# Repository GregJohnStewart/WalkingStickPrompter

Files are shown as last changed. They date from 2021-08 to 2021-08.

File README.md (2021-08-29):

# WalkingStickPrompter

A walking stick tele-prompter.

## Usage

### SD Card

The SD card has several "gotcha's":

- Must be formatted as `FAT` (preferably `FAT16`, but `FAT32` should work as well) 
- Directories currently not supported
- Keep the SD relatively clean, not too many files. For file selection need all the file names read in and there isn't a ton or RAM to go around!
  - One shouldn't have more than 13 `.txt` files available, as the menu system doesn't currently support scrolling

Resources:

- https://www.arduino.cc/en/Reference/SDCardNotes

### Files

These are guidelines for files that are on the sd card. For the device to operate properly, you must keep these things in mind.

- File names:
  - Case insensitive; `hello.txt` will be seen the same as `Hello.txt` and the board will get confused.
  - can only be 8 characters long, or will be shortened artificially in the display. Unfortunately, with the tech used there isn't a way around this.
  - sometimes a file can get weird, and fail to read. try renaming it.
- File Formats:
  - Currently, only `.txt` files are accepted.
  - The files must be pre-formatted before they will display correctly
    - Essentially, newlines will mess up how the text is displayed on the screen, moving all text under the newline down (and out of view)
    - There is a tool though for formatting the files appropriately: [Formatter](Formatter.html)
- The device will save the options set by the user to the SD card using the `OPS.DAT` file. This is not meant to be edited manually, but can be deleted to reset the options to default.

Resources:

- https://www.arduino.cc/en/Reference/SDCardNotes

### Battery

On preliminary measurements, will full brightness and smallest text size, the device lasted ____ on a 1200mAh battery.

To charge the battery, simply plug the main board into the computer or phone charger, with the battery plugged in and on (if a switch was added between the battery and the board). The main board will handle charging the battery.

The Orange light on the board is an indicator for charging status:

- Off = Not charging, fully charged
- On = Charging
- Flashing = No battery connected

More information here: https://learn.adafruit.com/adafruit-feather-328p-atmega328-atmega328p/power-management

### How to Use

The board uses a simple menu system to navigate. When the device is powered on, it first displays a splash screen. After that, it will go into the file select menu.

#### File Selection

This menu shows all valid and available text files for reading.

Use <kbd>Up</kbd> or <kbd>Down</kbd> to highlight a file, <kbd>Right</kbd> to select it (moving into file reading).

Pressing <kbd>Left</kbd> will send you to the Options Menu

#### File Reading

When reading a file, it will simply display one page of file content at a time.

- <kbd>Down</kbd> will load the next page

- <kbd>Up</kbd> will load the previous page
- <kbd>Left</kbd> will send you back to File Selection

#### Options Menu

The Options menu will let you change the presentation of text when reading files in.

Use <kbd>Up</kbd> or <kbd>Down</kbd> to highlight an option to change, <kbd>Right</kbd> to select it (moving to that option's specific menu).

Pressing <kbd>Left</kbd> will send you back to File Select.

##### Text Size

The text size menu will change the size of the text when file reading.

Use <kbd>Up</kbd> or <kbd>Down</kbd> to cycle through the available sizes, <kbd>Right</kbd> to set the size to the current one shown.

Pressing <kbd>Left</kbd> will send you back to the Options menu without saving changes.

##### Text Color

The text size menu will change the color of the text when file reading.

Use <kbd>Up</kbd> or <kbd>Down</kbd> to hilight the available colors, <kbd>Right</kbd> to set the color to the current one selected.

Pressing <kbd>Left</kbd> will send you back to the Options menu without saving changes.

##### Backlight

The text size menu will change the backlight level of the screen.

Use <kbd>Up</kbd> or <kbd>Down</kbd> to cycle through the available brightnesses, <kbd>Right</kbd> to set the brightness to the current one shown.

Pressing <kbd>Left</kbd> will send you back to the Options menu without saving changes.

## Build Documentation

### Bill of Materials

- [Adafruit Feather 328P](https://learn.adafruit.com/adafruit-feather-328p-atmega328-atmega328p/overview)
- [2.2" 18-bit color TFT LCD display with microSD card breakout](https://www.adafruit.com/product/1480)
- 4 momentary switches, or a d-pad
- 1 snap switch for battery (optional)

### Resources

- [Adafruit Feather 328P Pinouts](https://learn.adafruit.com/adafruit-feather-328p-atmega328-atmega328p/pinouts)
- [Adafruit 2.2" TFT Display with SD Card Reader](https://learn.adafruit.com/2-2-tft-display)
  - https://learn.adafruit.com/2-2-tft-display/adafruit-gfx-library
  - 
- [Adafruit ILI9341 Arduino Library](https://github.com/adafruit/Adafruit_ILI9341)
  - https://github.com/adafruit/Adafruit_ILI9341/blob/master/Adafruit_ILI9341.h
  - 
  - https://learn.adafruit.com/adafruit-gfx-graphics-library/overview
  - https://learn.adafruit.com/adafruit-gfx-graphics-library?view=all
  - https://www.arduino.cc/en/Reference/TFTSetTextSize
- [Arduino SD Library](https://github.com/arduino-libraries/SD)
  - https://github.com/arduino-libraries/SD/blob/master/src/utility/SdFile.cpp
  - https://github.com/arduino-libraries/SD/blob/master/src/File.cpp
  - https://github.com/adafruit/SD/blob/master/examples/Files/Files.ino
  - https://www.arduino.cc/en/Reference/SD
    - https://www.arduino.cc/en/Reference/FileRead
    - https://www.arduino.cc/en/Reference/FileSeek
- [Arduino Data Types](https://www.tutorialspoint.com/arduino/arduino_data_types.htm)
- [Adafruit TFT Display Example](https://github.com/adafruit/Adafruit_ILI9341/blob/master/examples/graphicstest/graphicstest.ino)
- [Adafruit Graphics Primitives](https://learn.adafruit.com/adafruit-gfx-graphics-library/graphics-primitives)
- Adafruit SD examples in the IDE
- https://learn.adafruit.com/adafruit-micro-sd-breakout-board-card-tutorial/arduino-library
- https://www.arduino.cc/reference/en/language/functions/communication/serial/print/
- https://create.arduino.cc/projecthub/muhammad-aqib/arduino-button-tutorial-using-arduino-digitalread-function-08adb5
- https://forum.arduino.cc/t/passingpassing-f-string-as-a-parameter/108984
- https://cpp4arduino.com/2020/02/07/how-to-format-strings-without-the-string-class.html
- https://www.geeksforgeeks.org/readwrite-class-objects-fromto-file-c/
- https://www.arduino.cc/reference/en/language/variables/data-types/stringobject/
- My Forum posts:
  - https://forum.arduino.cc/t/f-macro-garbled-c-string/896971
  - https://forums.adafruit.com/viewtopic.php?f=57&t=182150&p=885279#p885279
  - https://forums.adafruit.com/viewtopic.php?f=47&t=182033&p=885513#p885513
  - https://electronics.stackexchange.com/questions/580450/correct-wiring-for-adafruit-2-2-tft-display-w-sd-card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

### Environment Setup

1. Arduino IDE Setup
   1. Board Selection
      - Board: `Arduino Pro or Arduino Pro Mini`
      - Processor: `ATMega328P (3.3V, 8 MHz)`
   2. Required Libs
      - [Adafruit BusIO Library](https://github.com/adafruit/Adafruit_BusIO)
      - [AdaFruit GFX Library](https://github.com/adafruit/Adafruit-GFX-Library)
      - [Adafruit ILI9341 Library](https://github.com/adafruit/Adafruit_ILI9341)
      - [LinkedList](https://github.com/ivanseidel/LinkedList)
        - I needed to delete the `test.cpp` file in the library's directory for it to work.

### Circuitry

Realistic circuit diagram:

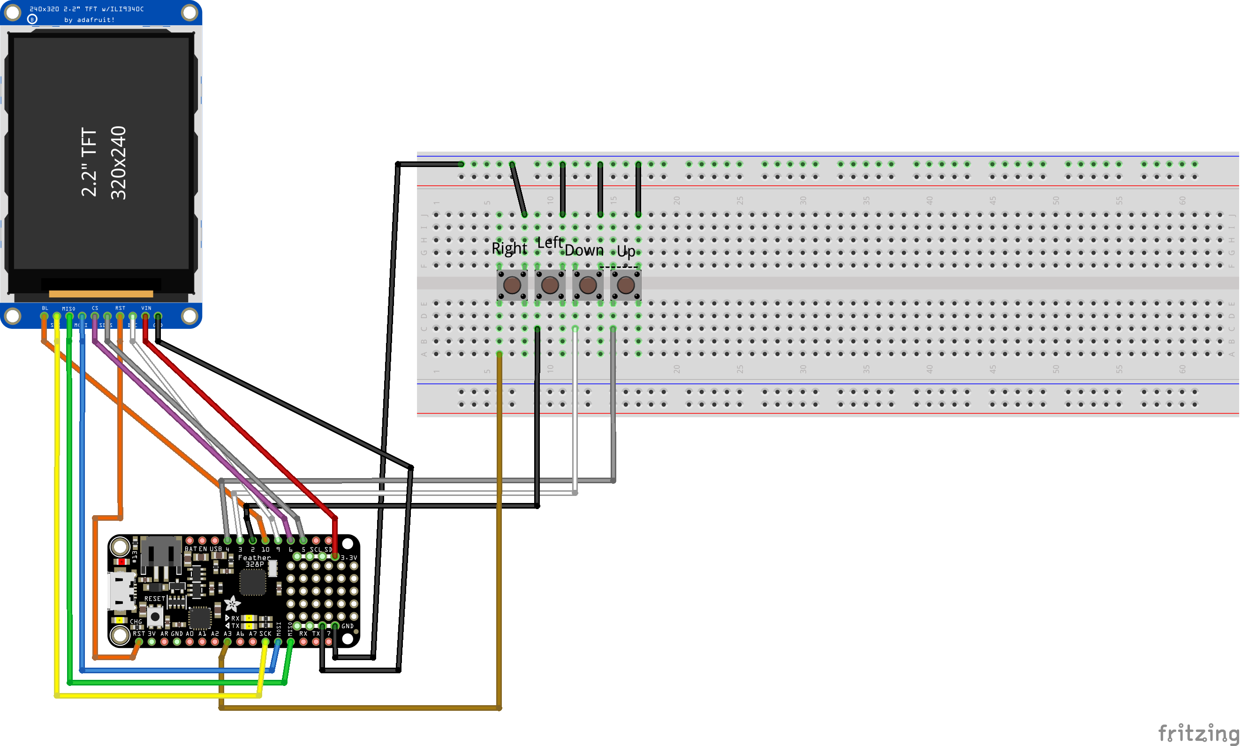
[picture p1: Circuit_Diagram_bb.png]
Realistic circuitry view


Schematic view:

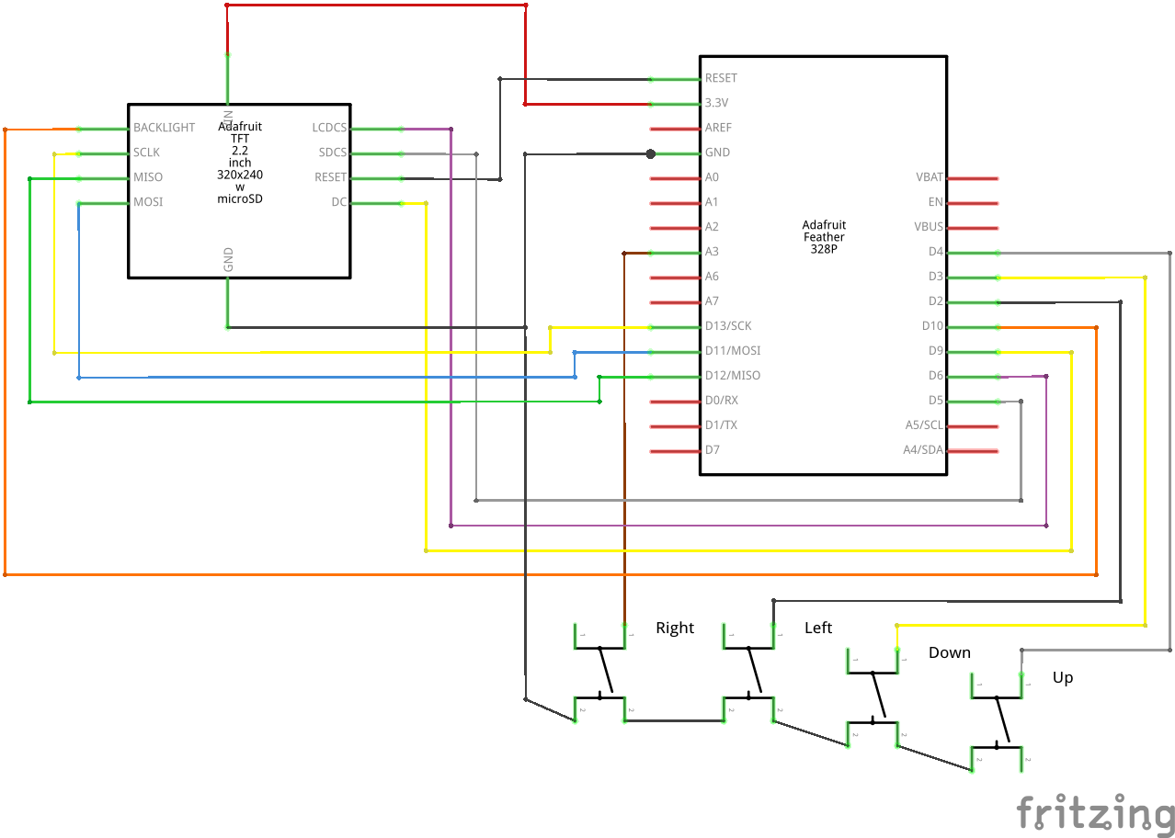
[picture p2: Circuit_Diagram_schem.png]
Schematic View


### Additional

#### Fritzing

Requires the addition of the Adafruit resource pack:

https://learn.adafruit.com/using-the-adafruit-library-with-fritzing/import-the-library-into-fritzing

## Future TODOs:

- Support directories
- Show images on the TFT (requires different microcontroller board with more program space/ RAM!)
- Menu code support scrolling
- Support measuring battery: https://learn.adafruit.com/adafruit-feather-328p-atmega328-atmega328p/power-management
- Have a status screen during reading mode, show battery and progress stats. Navigation aides?

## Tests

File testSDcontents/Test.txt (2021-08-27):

Hello World 1Hello World 2Hello World 3Hello World 4Hello World 5Hello World 6Hello World 7Hello World 8Hello World 9Hello World 10Hello World 11Hello World 12Hello World 13Hello World 14Hello World 15Hello World 16Hello World 17Hello World 18Hello World 19Hello World 20Hello World 21Hello World 22Hello World 23Hello World 24Hello World 25Hello World 26Hello World 27Hello World 28Hello World 29Hello World 30Hello World 31Hello World 32Hello World 33Hello World 34Hello World 35Hello World 36Hello World 37Hello World 38Hello World 39Hello World 40Hello World 41Hello World 42Hello World 43Hello World 44Hello World 45Hello World 46Hello World 47Hello World 48Hello World 49Hello World 50Hello World 51Hello World 52Hello World 53Hello World 54Hello World 55Hello World 56Hello World 57Hello World 58Hello World 59Hello World 60

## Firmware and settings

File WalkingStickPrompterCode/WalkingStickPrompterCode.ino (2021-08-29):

/**
   Main code for the WalkingStick Prompter.
   Author: Greg Stewart

   https://github.com/GregJohnStewart/WalkingStickPrompter
*/
#include "globals.h"
#include "statusLogHelpers.h"
#include "buttonHelpers.h"
#include "MenuEntry.h"
#include "menuEntryHelpers.h"
#include "tftHelpers.h"
#include "sdHelpers.h"
#include "screenSizeHelpers.h"
#include "optionsHelpers.h"

void setup() {
  DONE_STR = F("Done.");
  // Setup, turn on status light during setup
  pinMode(STATUS_LED, OUTPUT);
  pinMode(TFT_CS, OUTPUT);
  pinMode(SD_CS, OUTPUT);
  pinMode(TFT_BACKLIGHT, OUTPUT);
  analogWrite(TFT_BACKLIGHT, 255);
  
  turnStatusLightOn();

  Serial.begin(SERIAL_LOG_BAUD);
  if(!Serial){
    SERIAL_LOGS_ENABLED = false;
  }
  
  writeSerialLine(F("\n\n\nBegin Setup"));
  CUR_TAB_LEVEL++;

  setupButtons();

  //writeSerialLine(F("Done Setting up Buttons."));
  
  //setup TFT display, display something simple
  setupTft();


  //setup SD card info
  setupSD();
  
  //read options in
  readOptions();

  //display basic infos
  displaySplashScreen();

  // done with setup
  turnStatusLightOff();
  
  outFreeRam();

  CUR_TAB_LEVEL--;
  writeSerialLine(DONE_STR);
  delay(1000);
  analogWrite(TFT_BACKLIGHT, OPTIONS.backlightLevel);
  TFT.fillScreen(ILI9341_BLACK);
  TFT.setTextColor(ILI9341_WHITE, ILI9341_BLACK);
  TFT.setTextSize(MENU_FONT_SIZE);
}

/**
   Logic goes as follows:

    1. quick check for TFT/SD operability.
      - if either not, blink status led accordingly, wait 2.5 seconds, and go around
    2. Display all files
    3. wait for input
      - up/down, scroll file selection
      - yes button, show file
        - scroll enable through file
        - no button, done, back around
      - no button, show options
        - scroll through options, set as needed
        - no button, done, back around
    4. Done
*/
byte curVal = 0;
void loop() {
  //writeSerialLine(F("START program cycle"));
  //CUR_TAB_LEVEL++;
  outFreeRam();

  const String fileChosen = selectFile();
  outFreeRam();
  
  if(fileChosen.length() > 0){
    writeSerial(F("Chose file: "));
    writeSerialLine(fileChosen.c_str());
    
    readFileContent(fileChosen);
  } else {
    doOptions();
  }
  
  outFreeRam();
  //CUR_TAB_LEVEL--;
  //writeSerialLine(F("END program cycle."));
}


  /* Screen resolutions *
  TFT.fillScreen(ILI9341_BLACK);
  delay(500);
  TFT.setCursor(0, 0);
  TFT.setTextSize(temp);
  
  
  TFT.print(temp);
  for(int i = 2; i < getNumChars(temp); i++){
    TFT.print("_");
  }
  TFT.print("!");
  temp++;
  
  if(temp == 6){
    temp = 1;
  }
  /* */
  
  

  /* Button pressing *
  TFT.fillScreen(ILI9341_BLACK);
  TFT.setCursor(0, 0);
  TFT.print("Waiting for button press...");
  
  temp = waitForButtonPress();
  
  TFT.setCursor(0, 0);
  TFT.fillScreen(ILI9341_BLACK);
  TFT.print(String(temp) + " Was Pressed!");
  delay(2000);
  /* */

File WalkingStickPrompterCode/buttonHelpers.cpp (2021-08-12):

#include "Arduino.h"
#include "globals.h"

// the debounce time; increase if the output flickers
const unsigned long debounceDelay = 25;
const unsigned int PRESSED_READING = LOW;

bool testTimeout(unsigned long start, unsigned long cur, unsigned long timeout){
  
  return cur - start <= timeout;
}
bool testTimeout(unsigned long start, unsigned long timeout){
  return testTimeout(start, millis(), timeout);
}

bool readButtonState(int button){
  int reading = digitalRead(button);
  // read the state of the switch into a local variable:
  //Serial.println("\tButton reading: " + String(reading));

  if(reading != PRESSED_READING){
    //Serial.println("\tButton was not pressed");
    return false;
  }
    //Serial.println("\tButton was pressed");
  unsigned long initialTime = millis();
  do {
    reading = digitalRead(button);
    if(reading != PRESSED_READING){
      //Serial.println("\tButton not actually pressed");
      return false;
    }
  } while(testTimeout(initialTime, debounceDelay));
  //Serial.println("\tStill pressed");

  return true;
}

/**
 * 
 * @param timeout the length of time to ait for a button press. -1 for indefinately
 * @return the button value, or -1 if timed out
 */
int waitForButtonPress(unsigned long timeout){
  unsigned long startTime = millis();
  
  //writeSerialLine(F("Waiting for button press..."));
  //CUR_TAB_LEVEL++;
  
  do{
    for (int i = 0; i < sizeof BUTT_ARR / sizeof BUTT_ARR[0]; i++) {
      //Serial.println("Testing button: " + String(BUTT_ARR[i]));
      if(readButtonState(BUTT_ARR[i])){
      	  //writeSerialLine("Button was pressed: " + BUTT_ARR[i]);
          //CUR_TAB_LEVEL--;
        return BUTT_ARR[i];
      }
    }
  }while(timeout == -1 || testTimeout(startTime, timeout));
  
  //writeSerialLine(F("Timed out."));
  //CUR_TAB_LEVEL--;
  
  return -1;
}

int waitForButtonPress(){
  return waitForButtonPress(-1);
}

void setupButtons(){
  pinMode(UP_BUTTON, INPUT_PULLUP);
  pinMode(DOWN_BUTTON, INPUT_PULLUP);
  pinMode(LEFT_BUTTON, INPUT_PULLUP);
  pinMode(RIGHT_BUTTON, INPUT_PULLUP);
}

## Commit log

2021-08-07 first basic setup of project, betting some boilerplate done
    [Circuit Diagram.fzz]
2021-08-07 Added code for handling button presses
2021-08-10 Got basic utilities going for printing chars on screen
2021-08-11 More tweaks and attempts at button functionality
    [Circuit Diagram.fzz]
2021-08-12 added preliminary code for sd card
    [Circuit Diagram.fzz]
2021-08-13 Now properly listing files, can move the selector.
    [Circuit Diagram.fzz]
2021-08-25 Completed file selection, fixed memory leaks
    [WalkingStickPrompterCode.ino]
2021-08-28 Board functionality done
2021-08-29 Final tweaks and bugfixes.
    [WalkingStickPrompterCode.ino]
2021-08-29 Made updates to Circuit Diagrams
    [Circuit_Diagram.fzz]
2021-08-29 Updated Circuit diagram
    [Circuit_Diagram.fzz]
2021-08-29 Finished circuit diagrams
    [Circuit Diagram.fzz, Circuit_Diagram.fzz]
